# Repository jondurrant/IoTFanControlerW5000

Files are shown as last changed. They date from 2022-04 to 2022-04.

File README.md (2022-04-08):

# IoTFanControlerW5000
IOT Fan Controller based on RP2040 W5000 board from WizNet([WizNet W5100S Rp2040](https://www.wiznet.io/product-item/w5100s-evb-pico/))

Controls PWM fan based on environment temperature read through a DS18B20 sensor. Uses three presets to select fan speed, and a night time override speed to reduce night time noise.

Device is based on my TwinThing framework (see [twinThingRP2040W5x00](https://github.com/jondurrant/twinThingRP2040W5x00) and [TwinThingPyMQTT](https://github.com/jondurrant/TwinThingPyMQTT)). The device does not persist status or configuration in flash memory but instead publishes its state to a MQTT shadow service, which can update the device to current configuration when it attaches to the network.

# Hardware
+ [WizNet W5100S Rp2040](https://www.wiznet.io/product-item/w5100s-evb-pico/)
+ RGB Common Cathode LED
+ 3x Resistors 91R
+ DS20B18 temperature sensor
+ Resistor 4.7K
+ RotaryEncoder with Push Switch
+ 2x 10nF Capacitor for smoothing
+ OLED display 128x32 SSD1306
+ 2x 80mm 12V PWM controllable fans

# Dependencies
## C++
+ [FreeRTOS-Kernel](https://github.com/FreeRTOS/FreeRTOS-Kernel): Task management
+ [FreeRTOS-CoreMQTT-Agent](https://www.freertos.org/mqtt-agent/index.html): MQTT Library
+ [ioLibary_Driver](https://github.com/Wiznet/ioLibrary_Driver): Drivers for W5100s
+ [twinThingRP2040W5x00](https://github.com/jondurrant/twinThingRP2040W5x00)
+ [json-maker](https://github.com/rafagafe/json-maker): JSON writing for comms
+ [tiny-json](https://github.com/rafagafe/tiny-json): JSON parser
+ [RP2040PIO-DS18B20](https://github.com/jondurrant/RP2040PIO-DS18B20): Sensor library
+ [pico-ssd1306](https://github.com/daschr/pico-ssd1306): Oled Driver
+ [RtosComponents](https://github.com/jondurrant/RtosComponents): Watchdog module

## MQTT hub
+ [EMQX](https://www.emqx.io/)

## MQTT Services
+ [TwinManager](https://github.com/jondurrant/TwinThingPyMQTT)

# Folder Structur

+ src - source code for the project
+ lib - libraries used by the project
+ port - port code needed for the libraries used by the project
+ patches - patch files produced by WizNet for the ioLibrary_Driver lib
+ py - test python to interact with the IOT devices
+ schematic - Circuit schematic (no PCB design as build on prototype board)
+ 3dModels - STL files for PCB bracket, fan cover, OLED housing and Rotary Encoder housing

# Clone and Build
## Clone
'''
git clone --recurse-submodules https://github.com/jondurrant/IoTFanControlerW5000
'''

## Build
'''
mkdir build
cd build
cmake ..
make
'''

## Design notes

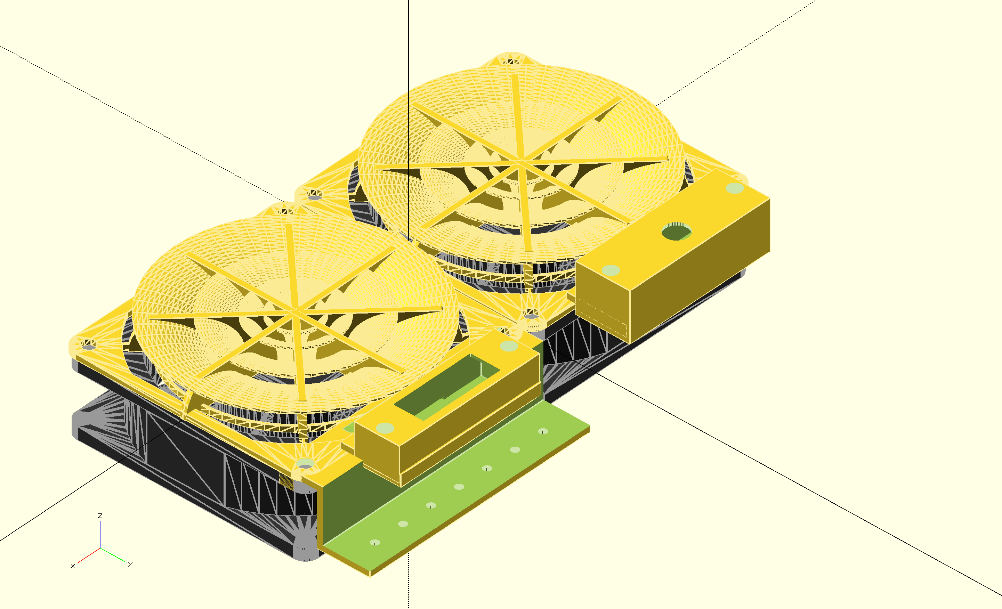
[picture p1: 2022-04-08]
3dModels/imgs/angle.png

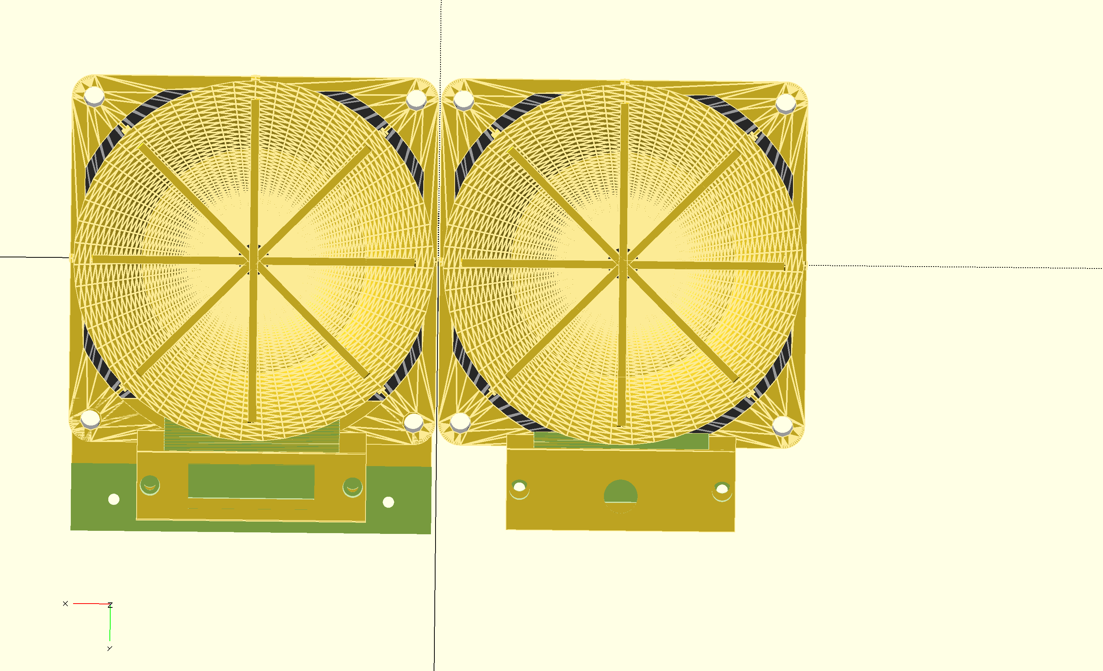
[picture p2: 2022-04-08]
3dModels/imgs/front.png

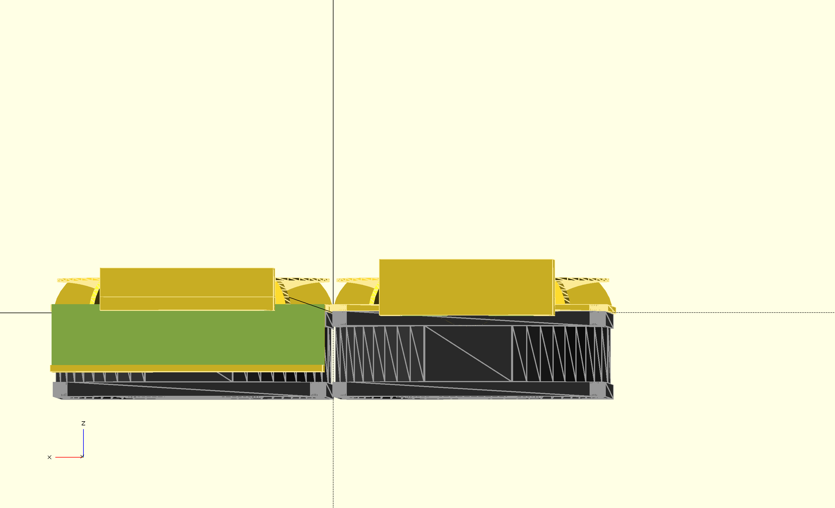
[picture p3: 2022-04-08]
3dModels/imgs/side1.png

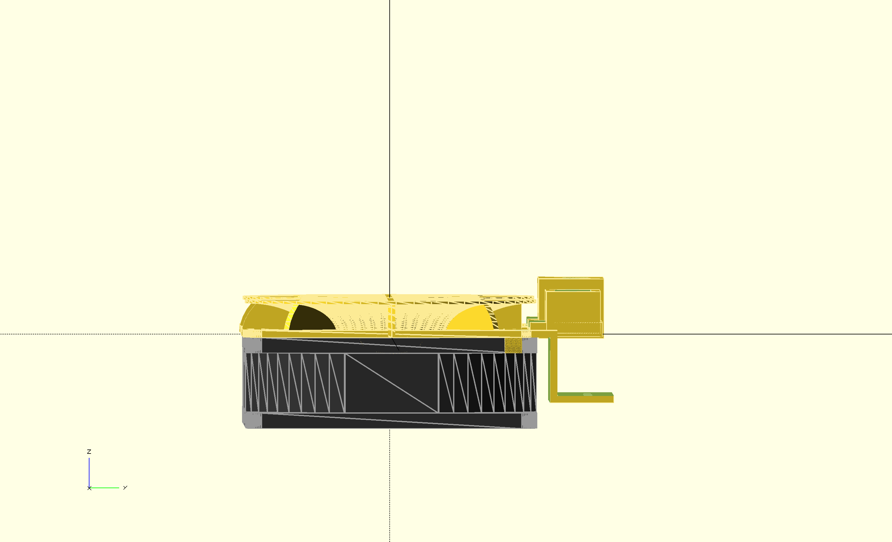
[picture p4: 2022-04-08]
3dModels/imgs/side2.png

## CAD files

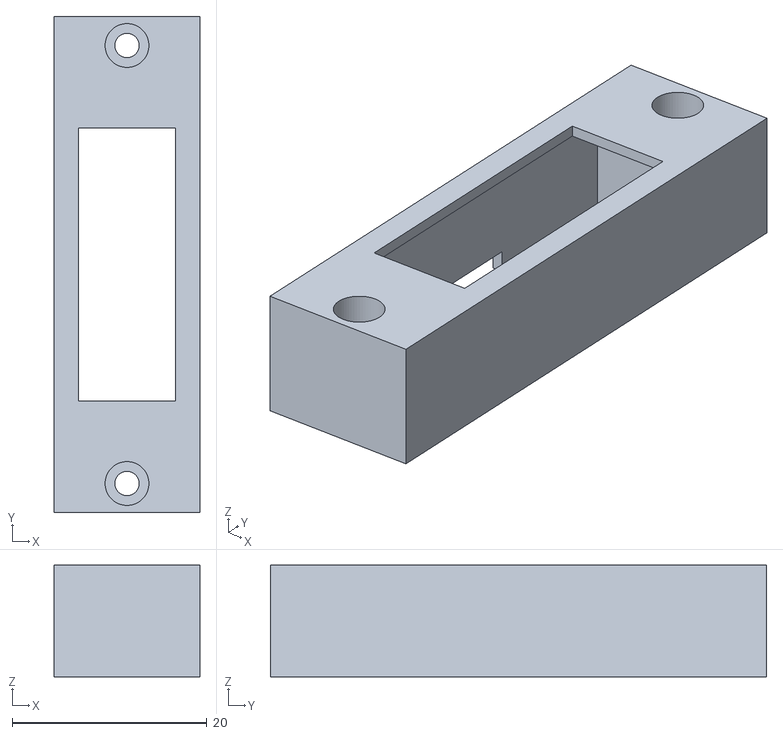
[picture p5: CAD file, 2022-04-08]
3dModels/oledHousing.stl
15.0 x 51.0 x 11.5

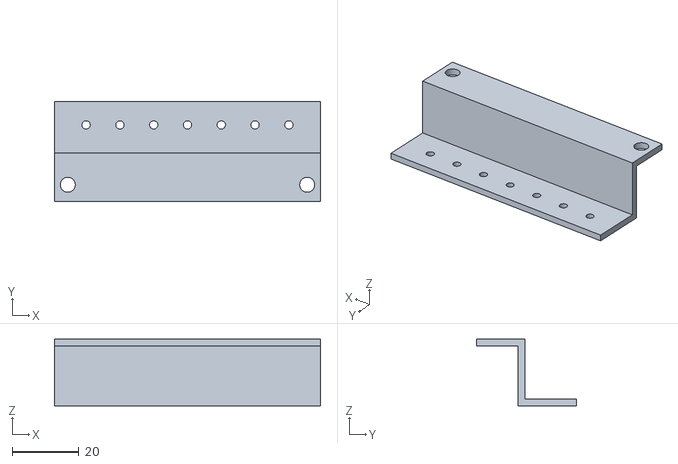
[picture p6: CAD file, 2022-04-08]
3dModels/bracket.stl
80.0 x 30.0 x 20.0

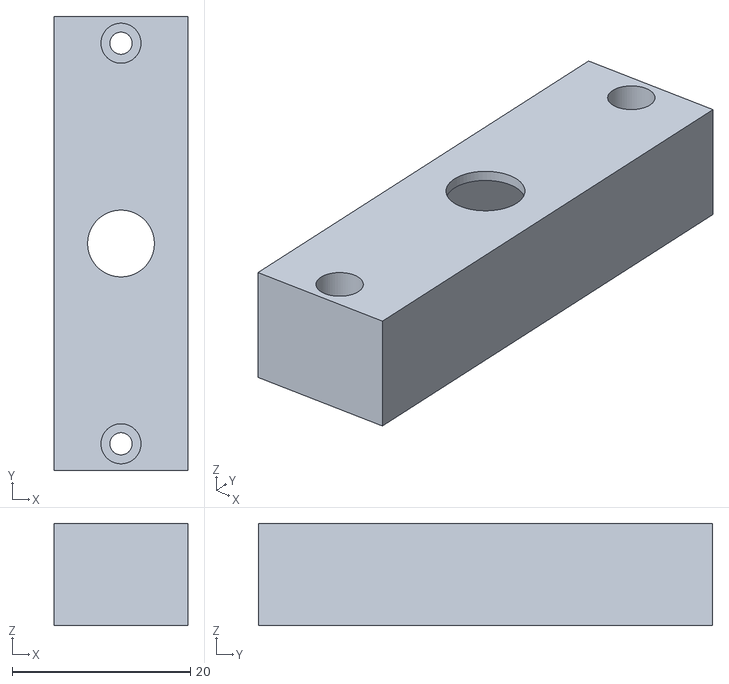
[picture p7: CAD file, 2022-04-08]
3dModels/rotEnvHousing.stl
15.0 x 51.0 x 11.5

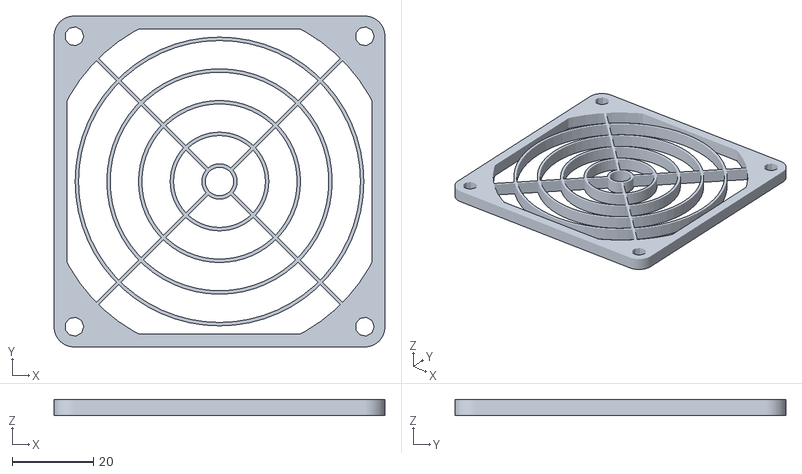
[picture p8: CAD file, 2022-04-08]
3dModels/fanGuard-Back.stl
81.5 x 81.5 x 4.00

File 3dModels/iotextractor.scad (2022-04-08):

use <../libs/openscad-rpi-library/misc_boards.scad>

/**
include <../libs/NopSCADlib/core.scad>
include <../libs/NopSCADlib/vitamins/fan.scad>
use <../libs/NopSCADlib/utils/layout.scad>
**/
include <../libs/NopSCADlib/lib.scad>  



THICK=2;
M5=5.5;
M4=4.5;
M3=3.5;
M2=2.5;
M3INSERT=3.7;
M2INSERT=3.4;

fanX=81;
fanY=81;
fanZ=26;
fanFix=35.7;

mountDep=5;


oledX=12;
oledY=38;
oledZ=3.5;
oledXD=5;

oledHouseX=oledX+THICK+1;
oledHouseY=oledY+THICK+1 + M2*4;
oledHouseZ=oledZ + 6 + THICK;


rotEncX=12;
rotEncY=38;
rotEncZ=3.5;
rotEncXD=5;

rotEncHouseX=rotEncX+THICK+1;
rotEncHouseY=rotEncY+THICK+1 + M2*4;
rotEncHouseZ=rotEncZ + 6 + THICK +5;

bracketW=30;
bracketD=20;
bracketL=80;
pcbPitch=2.54;

//fan_guard(fan80x25, name = false, thickness = THICK*2);
//translate([0,0,3])
//    oled();

fans();
bracket();

translate([-41,0,0]){
    rotate([0,0,90])
        guard();
}
translate([-41,50,(oledHouseZ+THICK)/2]){
    rotate([0,0,90])
        rotEncHouse();
}



translate([41,0,0]){
    rotate([0,0,90])
        guard();
}
translate([41,50,(oledHouseZ+THICK)/2]){
    rotate([0,0,90])
        oledHouse();
}



translate([50,0,(oledHouseZ+THICK)/2]){
//   oledHouse();
//    rotEncHouse();
}

module oled(){
    color("blue"){
        translate([0,0,(oledZ)/2])
            cube([oledX, oledY-(oledXD*2), 1], center=true);
        cube([oledX, oledY, oledZ-1], center=true);
        translate([0,(oledY-2.5)/2,5/(-2)])
            cube([oledX, 2.5, 5], center=true);
        translate([0,oledY/2-9,-5])
            cube([oledX,18,1], center=true);
    }
}


module oledHouse(){
    difference(){
        cube([oledHouseX, oledHouseY, oledHouseZ], center=true);
        cube([oledX- 2, oledY- (oledXD*2), oledHouseZ*2], center=true);
        translate([0, 0, THICK/(-2)])
            cube([oledX+1, oledY+1, oledHouseZ], center=true);
        
        for (i=[-1,1]){ 
            translate([0, (oledY/2 + M3)*i, 0]){
                cylinder(d=M2, h=oledHouseZ*2, center=true);
                translate([0, 0, 4])
                    cylinder(d=M4, h=oledHouseZ, center=true);
            }
        }
        
        translate([-6,0,oledHouseZ/(-2)]){
            cube([12,12,THICK*2],center=true);
        }
    }
}



module fans(){
    translate([0,0,25/(-2)]){
        translate([-41,0,0])
            fan(fan80x25);
        translate([41,0,0])
            fan(fan80x25);
    }
    
    //translate([0,0,50])
    //fan_guard(fan80x25, name = false, thickness = THICK);
}


module t(){
    difference(){
        translate([0,0,3/2])
            cylinder(r=2.5,h=3,center=true);
        rotate_extrude(convexity = 10)
            translate([2, 0, 0])
                circle(r = 1, $fn = 100);
        
    }
}


module guard(){
    fan_guard(fan80x25, name = false, thickness = THICK);
    
    resize(newsize=[80,80,10])
        blade();
    resize(newsize=[50,50,10])
        blade();
    resize(newsize=[28,28,10])
        blade();
    
    resize(newsize=[16,16,10])
        blade();
    
    
    intersection(){
        translate([0,0,THICK/2*5]){
            for (a=[0,45,135]){
                rotate([0,0,a])
                    cube([THICK, 82, THICK*5], center = true);
            }
            translate([-5,0,0]){
                rotate([0,0,90])
                    cube([THICK, 82, THICK*5], center = true);
            }
        }
        scale([1,1,0.5])
                sphere(d=82);
    }
    
    translate([48,0,THICK]){
        difference(){
            cube([oledHouseX+5, oledHouseY, THICK*2], center=true);
            translate([-5,0,THICK])
                cube([oledHouseX+5, oledHouseY-12, THICK*2], center=true);
            for (i=[-1,1]){ 
            translate([1, (oledY/2 + M3)*i, 0]){
                cylinder(d=M2INSERT, h=oledHouseZ*2, center=true);
            }
        }
        }
    }
}



module blade(){
    rotate_extrude(convexity = 10)
            translate([2, 0, 0])
                intersection(){
                    difference(){
                        circle(r = 1, $fn = 100);
                        circle(r = 0.9, $fn = 100);
                    }
                    translate([-1,1,1])
                        square([2,2],center=true);
                };
}




module rotEncHouse(){
    difference(){
        cube([rotEncHouseX+3, rotEncHouseY, rotEncHouseZ], center=true);
        translate([pcbPitch/2,0,0])
            cylinder(d=7.5, h=rotEncHouseZ*2, center=true);
        translate([0, 0, THICK/(-2)])
            cube([rotEncX+3, rotEncY+1, rotEncHouseZ], center=true);
        
        for (i=[-1,1]){ 
            translate([0, (rotEncY/2 + M3)*i, 0]){
                cylinder(d=M2, h=rotEncHouseZ*2, center=true);
                translate([0, 0, 4])
                    cylinder(d=M4, h=rotEncHouseZ, center=true);
            }
        }
        
        translate([-6,0,rotEncHouseZ/(-2)]){
            cube([12,12,THICK*2],center=true);
        }
    }
}


module bracket(){
    translate([41,46,(bracketD/-2)+THICK]){
        difference(){
            cube([bracketL, bracketW, bracketD], center=true); 
            
            //Front 90Deg
            translate([0,-10,THICK*(-1)]){
                cube([bracketL*1.5, bracketW/2, bracketD], center=true);
            }
            
            //Back 90Deg
            translate([0,10,THICK*(1)]){
                cube([bracketL*1.5, bracketW/2+THICK*3, bracketD], center=true);
            }
            
            //PCB Mount
            for (i=[0:pcbPitch*4:40]){
                for (j=[-1,1]){
                    translate([0+i*j,8,0]){
                        cylinder(d=M2, h=bracketD*2, center=true);
                    }
                }
            }
            
            //Fan Fixing
            for (i=[1,-1]){
                translate([36*i,-10,0]){
                    cylinder(d=M4, h=bracketD*2, center=true);
                }
            }
        }
        
    }
}

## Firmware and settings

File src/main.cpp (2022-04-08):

/**
 * ----------------------------------------------------------------------------------------------------
 * Includes
 * ----------------------------------------------------------------------------------------------------
 */
//Std
#include <stdio.h>
#include <stdlib.h>
#include <string.h>

//RP2040
#include "hardware/watchdog.h"
#include "hardware/rtc.h"


//W5000 and FreeRTOS
extern "C" {
#include <FreeRTOS.h>
#include <task.h>
#include <semphr.h>

#include "port_common.h"

#include "wizchip_conf.h"
#include "w5x00_spi.h"

#include "dhcp.h"
#include "dns.h"

#include "timer.h"
#include "socket.h"
}


//JD Specials
#include <WatchdogBlinkAgent.h>
#include <RGBLEDAgent.h>
#include "OledDisplay.h"

//TwinThing
#include "EthHelper.h"
#include "MQTTAgent.h"
#include "MQTTRouterPing.h"
#include "MQTTRouterTwin.h"

// Fan Control Classes
#include "FanState.h"
#include "RGBLEDMgr.h"
#include "FanController.h"
#include "DisplayAgent.h"
#include "RotEncAgent.h"
#include "RotEncListener.h"

/**
 * ----------------------------------------------------------------------------------------------------
 * Definitions
 * ----------------------------------------------------------------------------------------------------
 */
/* Task */
#define DHCP_TASK_STACK_SIZE 2048
#define DHCP_TASK_PRIORITY 8

#define DNS_TASK_STACK_SIZE 512
#define DNS_TASK_PRIORITY 10

/* Clock */
#define PLL_SYS_KHZ (133 * 1000)


/* Socket */
#define SOCKET_DHCP 0
#define SOCKET_DNS 3

/* Retry count */
#define DHCP_RETRY_COUNT 5
#define DNS_RETRY_COUNT 5


#ifndef MQTTHOST
#define MQTTHOST "mqtt.home.com"
#define MQTTPORT 1883
#define MQTTUSER "MAC"
#define MQTTPASSWD "MAC"
#endif


/**
 * ----------------------------------------------------------------------------------------------------
 * Variables
 * ----------------------------------------------------------------------------------------------------
 */
/* Network */
static uint8_t g_ethernet_buf[ETHERNET_BUF_MAX_SIZE] = {
    0,
};

/*NTP Servers*/
static const char *sntpHosts[5] = {
		"mqtt.home.com",
		"uk.pool.ntp.org",
		"time.cloudflare.com",
		"ntp2a.mcc.ac.uk",
		"ntp2b.mcc.ac.uk"};

TaskHandle_t initHandle = NULL;

//Global Twin Objects
EthHelper gEth;
MQTTAgent mqttAgent = MQTTAgent(3, &gEth);
MQTTRouterTwin mqttRouter;

FanState state;
TwinTask xTwin;
MQTTPingTask xPing;

RGBLEDAgent ledAgent = RGBLEDAgent(5,3,2);
RGBLEDMgr   ledMgr = RGBLEDMgr(&ledAgent);

OledDisplay display = OledDisplay(14, 15);
DisplayAgent dispAgent = DisplayAgent(&display, &state, &gEth);

FanController fanControl = FanController(&state, 0);

RotEncAgent rotEncAgent = RotEncAgent(12, 11, 10, 20);
RotEncListener rotEncListener;

/**
 * ----------------------------------------------------------------------------------------------------
 * Functions
 * ----------------------------------------------------------------------------------------------------
 */

/* Clock */
static void set_clock_khz(void);


/***
 * Print status and stack usage of task
 * @param name
 * @param task
 */
void debugTask(char * name, TaskHandle_t task){
	TaskStatus_t xTaskStatus;
	char ready[]="eReady";
	char run[]="eRunning";
	char block[]="eBlocked";
	char sus[]="eSuspended";
	char del[]="eDeleted";
	char other[]="Unknown";
	char *state = other;


	vTaskGetInfo( task,
	              &xTaskStatus,
				  pdTRUE,
				  (eTaskState)eInvalid);

	switch(xTaskStatus.eCurrentState){
	case eReady:
		state = ready;
		break;
	case eRunning:
		state = run;
		break;
	case eBlocked:
		state = block;
		break;
	case eSuspended:
		state = sus;
		break;
	case eDeleted:
		state = del;
		break;
	default:
		state = other;
	}

	printf("%s: Priority: %d/%d Run: %d Min: %d eState: %s\n",
			name,
			xTaskStatus.uxCurrentPriority,
			xTaskStatus.uxBasePriority,
			xTaskStatus.ulRunTimeCounter,
			xTaskStatus.usStackHighWaterMark,
			state
			);
}


/***
 * Start up the MQTT components
 * @param mqttTarget - Host of MQTT Hub
 * @param mqttPort - Port number
 * @param mqttUser - User
 * @param mqttPwd - Password
 */
void doMQTT(char * mqttTarget, uint16_t mqttPort, char * mqttUser, char * mqttPwd){

	mqttAgent.credentials(mqttUser, mqttPwd);
	mqttRouter.init(mqttAgent.getId(), &mqttAgent);

	//Twin agent to manage the state
	xTwin.setStateObject(&state);
	xTwin.setMQTTInterface(&mqttAgent);
	xTwin.start(tskIDLE_PRIORITY+1);

	//Start up a Ping agent to mange ping requests
	xPing.setInterface(&mqttAgent);
	xPing.start(tskIDLE_PRIORITY+1);

	//Give the router the twin and ping agents
	mqttRouter.setTwin(&xTwin);
	mqttRouter.setPingTask(&xPing);

	//Setup and start the mqttAgent
	mqttAgent.setObserver(&ledMgr);
	mqttAgent.setRouter(&mqttRouter);

	mqttAgent.connect(mqttTarget, 1883, true, false);
	mqttAgent.start(tskIDLE_PRIORITY+2);//DHCP_TASK_PRIORITY);
}


/***
 * Init thread to get everything going and check on status of network
 * @param pvParameters
 */
void
init_thread(void* pvParameters) {
	char mqttTarget[] = MQTTHOST;
	uint16_t mqttPort = MQTTPORT;
	char mqttUser[] = MQTTUSER;
	char mqttPwd[] = MQTTPASSWD;
	uint8_t ip[4];
	bool retval;

	WatchdogBlinkAgent watchdog;
	watchdog.start(tskIDLE_PRIORITY+1);


	if (!ledAgent.start(tskIDLE_PRIORITY+1)){
		LogError(("Led Agent failed to start"));
	} else {
		LogInfo(("Led Agent Started"));
	}
	ledAgent.set(RGBModeOn,0xFF,0x0,0x0);

	ledMgr.setDisplayAgent(&dispAgent);
	dispAgent.start(tskIDLE_PRIORITY+1);

	rotEncAgent.setListener(&dispAgent);
	rotEncAgent.start(tskIDLE_PRIORITY+1);

	gEth.enableMutex();
	gEth.dhcpClient();
	gEth.getIPAddress(ip);
	dispAgent.showIP(ip);
	ledAgent.set(RGBModeOn,0xFF,0xCE,0x42);

	gEth.setSNTPServers(sntpHosts, 5);
	retval = gEth.syncRTCwithSNTP(sntpHosts, 5);
	printf("SNTP Res: %s\n", retval?"Ok":"Fail");

	doMQTT(mqttTarget, mqttPort, mqttUser, mqttPwd);

	uint32_t count=0;
	datetime_t xDate;
    for (;;){
    	vTaskDelay(1000);

    	/*
    	debugTask("ledAgent", ledAgent.getTask());
    	debugTask("watchdog", watchdog.getTask());
    	debugTask("mqttAgent", mqttAgent.getTask());
    	debugTask("xTwin", xTwin.getTask());
    	debugTask("xPing", xPing.getTask());
    	debugTask("init", initHandle);
    	debugTask("dispAgent", dispAgent.getTask());
    	debugTask("rotEncAgent", rotEncAgent.getTask());
    	*/

    	//Check if network has failed
    	if (!gEth.isJoined()){
    		dispAgent.noIP();
    		ledAgent.set(RGBModeOn,0xFF,0x0,0x0);
    		gEth.dhcpClient();
    		if (gEth.isJoined()){
				ledAgent.set(RGBModeOn,0xFF,0xCE,0x42);
				gEth.getIPAddress(ip);
				dispAgent.showIP(ip);
    		}
    	} else {

    		//Once a day renew the DHCP lease
			if (count >= 60*60*24){
				count = 0;

				if (gEth.dhcpClient()){
					printf("DHCP Renewed\n");
				} else {
					printf("DHCP FAILED Renew\n");
				}

				//And update RTC
				retval = gEth.syncRTCwithSNTP(sntpHosts, 5);
				printf("SNTP: %s\n", retval?"Ok":"Fail");
			}
    	}
    	count ++;

    	if (count % 10 == 0){
			state.updateClock();
    	}
    }
}

/**
 * ----------------------------------------------------------------------------------------------------
 * Main
 * ----------------------------------------------------------------------------------------------------
 */
int main()
{
    /* Initialize */
    set_clock_khz();

    stdio_init_all();


    //3second wait to let serial stabalise for debug messages
    sleep_ms(3000);

    if (watchdog_caused_reboot()){
    	printf("WATCHDOG REBOOTED\n");
    	sleep_ms(5000);

    }

    //Init ethernet before running up tasks
    gEth.rtcInit();
    gEth.init(g_ethernet_buf);

    //Nice message on display why waiting for network
    display.displayString("Hello","",2);


    //Launch Init task
    xTaskCreate(
		init_thread,
		"Init task",
		DHCP_TASK_STACK_SIZE,
		( void * ) 1,
		DHCP_TASK_PRIORITY,//tskIDLE_PRIORITY+1,
		&initHandle );

    vTaskStartScheduler();

    //Should never get here
    while (1)
    {
        ;
    }
}


/* Clock */
static void set_clock_khz(void)
{
    // set a system clock frequency in khz
    set_sys_clock_khz(PLL_SYS_KHZ, true);

    // configure the specified clock
    clock_configure(
        clk_peri,
        0,                                                // No glitchless mux
        CLOCKS_CLK_PERI_CTRL_AUXSRC_VALUE_CLKSRC_PLL_SYS, // System PLL on AUX mux
        PLL_SYS_KHZ * 1000,                               // Input frequency
        PLL_SYS_KHZ * 1000                                // Output (must be same as no divider)
    );
}

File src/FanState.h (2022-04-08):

/*
 * FanState.h
 *
 * Fan State
 *
 *  Created on: 14-Mar- 2022
 *      Author: jondurrant
 */

#ifndef FANSTATE_H_
#define FANSTATE_H_

#include <MQTTConfig.h>
#include "StateTemp.h"
#include <stdbool.h>
#include <stdint.h>
#include <DS18B20.h>

#define FAN_ON_SLOT 		3
#define FAN_DAY_END_SLOT 	4
#define FAN_DAY_START_SLOT	5
#define FAN_DAY_SLOT 		6
#define FAN_CLOCK_SLOT		7
#define FAN_CSPEED_SLOT		8
#define FAN_MAX_NIGHT_SLOT	9
#define FAN_PRE_TEMP_SLOT	10
#define FAN_PRE_SPEED_SLOT	11
#define FAN_ENV_TEMP_SLOT	12
#define FAN_OVERRIDE_SLOT	13


#define FAN_PRESETS 3

/***
 * State include temperate, Fan Speed
 */
class FanState: public StateTemp {
public:
	FanState();
	virtual ~FanState();

	/***
	 * calculate Speed
	 * @return
	 */
	void calcSpeed();

	/***
	 * Gets the On status of the fan
	 * @return
	 */
	bool getOn() const;

	/***
	 * Sets the on status of the fan
	 * @param b
	 */
	void setOn(bool b);

	/***
	 * Returns hour at which Day Ends
	 * @return
	 */
	uint8_t getDayEnd() const ;

	/***
	 * Sets hour at which day ends
	 * @param DayEnd
	 */
	void setDayEnd(uint8_t xDayEnd = 21) ;

	/***
	 * Get Start Day Hour
	 * @return start hour
	 */
	uint8_t getDayStart() const ;

	/***
	 * Sets Day start hour
	 * @param xDayStart
	 */
	void setDayStart(uint8_t xDayStart = 7) ;

	/***
	 * Is in day mode
	 * @return
	 */
	bool isDay() const ;

	/***
	 * Set day mode
	 * @param xDay
	 */
	void setDay(bool xDay = true) ;


	/***
	 * Get Environment Temperature (DS18B20)
	 * @return celsius
	 */
	float getEnvTemp();


	/***
	 * Set temp in celsius
	 * @param temp
	 */
	void setEnvTemp(float temp);

	/***
	 * Number of minutes left for fan speed override
	 * @return
	 */
	uint16_t getOverrideMinutes();

	/***
	 * Set number of minutes to override fan speed for
	 * @param min
	 */
	void setOverrideMinutes(uint16_t min);


	/***
	 * Update time and temp and trigger state update
	 */
	void updateClock();


	/***
	 * Get Current speed
	 * @return percentage 0 to 100
	 */
	uint8_t getCurrentSpeed();

	/***
	 * Set Current Speed
	 * @param percent: 0 to 100
	 */
	void setCurrentSpeed(uint8_t percent);

	/***
	 * Get Maximum speed to run at night
	 * @return perecntage 0 to 100
	 */
	uint8_t getMaxNightSpeed();

	/***
	 * Set Maximum speed to run at night
	 * @param percent - 0 to 100
	 */
	void setMaxNightSpeed(uint8_t percent);

	/***
	 * Get Temperate presets
	 * When temp < t[0] speed is zero
	 * When t[i] <= temp < t[i+1]: speed is speed[i[
	 * When temp > t[2]: speed is speed[2]
	 * @return uint8_t[3]
	 */
	const uint8_t * getPreTemp() const;

	/***
	 * Set Temperature presets
	 * @param temps - uint8_t[3]
	 */
	void setPreTemp(uint8_t* temps);

	/***
	 * Set specific temp preset
	 * @param temp - tempereature
	 * @param preset - 0 to 2.
	 */
	void setPreTemp(uint8_t temp, uint8_t preset);

	/***
	 * Get preset speed
	 * @return uintt_t[3], each value 0 to 100
	 */
	const uint8_t * getPreSpeed() const;

	/***
	 * Set preset speeds
	 * When temp < t[0] speed is zero
	 * When t[i] <= temp < t[i+1]: speed is speed[i[
	 * When temp > t[2]: speed is speed[2]
	 * @param speeds uint8_t[3] - each value 0 to 100
	 */
	void setPreSpeed(uint8_t* speeds);

	/***
	 * Set specific preset speed
	 * @param speed - 0 to 100
	 * @param preset 0 to 2
	 */
	void setPreSpeed(uint8_t speed, uint8_t preset);



	/***
	 * Update state data from a json structure
	 * @param json
	 */
	virtual void updateFromJson(json_t const *json);

	/***
	 * Retrieve state of object in JSON format
	 * @param buf - buffer to write to
	 * @param len - length of buffer
	 * @return length of json or zero if we ran out of space
	 */
	virtual unsigned int state(char *buf, unsigned int len) ;


protected:
	/***
	 *  On status in JSON format
	 * @param buf
	 * @param len
	 * @return
	 */
	char* jsonOn(char *buf, unsigned int len);

	/***
	 *  Day Start Hour status in JSON format
	 * @param buf
	 * @param len
	 * @return
	 */
	char* jsonDayStart(char *buf, unsigned int len);

	/***
	 *  Day End Hour status in JSON format
	 * @param buf
	 * @param len
	 * @return
	 */
	char* jsonDayEnd(char *buf, unsigned int len);

	/***
	 *  Day in JSON format
	 * @param buf
	 * @param len
	 * @return
	 */
	char* jsonDay(char *buf, unsigned int len);

	/***
	 *  Time in JSON format
	 * @param buf
	 * @param len
	 * @return
	 */
	char* jsonClock(char *buf, unsigned int len);

	/***
	 *  Current Speed in JSON format
	 * @param buf
	 * @param len
	 * @return
	 */
	char* jsonCSpeed(char *buf, unsigned int len);

	/***
	 *  Max Night Speed in JSON format
	 * @param buf
	 * @param len
	 * @return
	 */
	char* jsonMSpeed(char *buf, unsigned int len);

	/***
	 *  Preset Temp in JSON format
	 * @param buf
	 * @param len
	 * @return
	 */
	char* jsonPreTemp(char *buf, unsigned int len);

	/***
	 *  Preset Speed in JSON format
	 * @param buf
	 * @param len
	 * @return
	 */
	char* jsonPreSpeed(char *buf, unsigned int len);

	/***
	 *  Preset Speed in JSON format
	 * @param buf
	 * @param len
	 * @return
	 */
	char* jsonEnvTemp(char *buf, unsigned int len);

	/***
	 * Fan speed override time in minutes JSON format
	 * @param buf
	 * @param len
	 * @return
	 */
	char* jsonOverrideMinutes(char *buf, unsigned int len);

private:
	//Is Fan on
	bool xOn = false;

	//Day start and end
	uint8_t xDayStart = 7;
	uint8_t xDayEnd = 21;
	bool xDay = true;

	//Fan Speed
	uint8_t xCSpeed = 100;
	uint8_t xMSpeed = 100;

	//Presets
	uint8_t xPreTemp[FAN_PRESETS];
	uint8_t xPreSpeed[FAN_PRESETS];

	//Environment temp read by DS18B20
	float xEnvTemp = 0.0;

	//Hardware interface
	DS18B20 xDS18B20 ;

	uint8_t xMin = 0;
	uint16_t xOverrideMinutes = 0;

};

#endif /* STATETEMP_H_ */

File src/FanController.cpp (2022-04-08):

/*
 * FanController.cpp
 *
 * PWM Fan Controller
 *
 *  Created on: 15 Mar 2022
 *      Author: jondurrant
 */

#include "FanController.h"
#include "hardware/pwm.h"


/***
 * Constructor
 * @param state - State object used to find speed
 * @param gp - GPIO number for PWM pin
 */
FanController::FanController(FanState *state, uint8_t gp) {
	xPin = gp;
	pState = state;

	pState->attach(this);

	 gpio_set_function(xPin, GPIO_FUNC_PWM);
	 uint slice_num = pwm_gpio_to_slice_num(0);
	 pwm_set_enabled(slice_num, true);
	 pwm_set_gpio_level	(xPin,0);
}

/***
 * Destructor
 */
FanController::~FanController() {
	// TODO Auto-generated destructor stub
}


/***
 * Notification of a change of a state item with the State object.
 * @param dirtyCode - Representation of item changed within state. Used to pull back delta
 */
void FanController::notifyState(uint16_t dirtyCode){
	if ((dirtyCode | FAN_CSPEED_SLOT) > 0){
		uint8_t speed = pState->getCurrentSpeed();

		uint16_t s = 0xffff/100;
		uint16_t minSpeed = s * 20;
		s = (0xffff - minSpeed)/100;
		s = (speed * s) + minSpeed;

		if (speed == 0){
			s = 0;
		}

		if (!pState->getOn()){
			s = 0;
		}
		pwm_set_gpio_level	(xPin, s);

	}
}

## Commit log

2022-03-15 RGB Status LED added
2022-03-15 Fan control added
2022-03-15 Fan control
2022-03-25 Added external DS18B20 temp sensor
2022-03-28 DisaplyAgent stack overflow resolved
    [main.cpp]
2022-03-28 Rotary Encoder framework added
2022-03-31 Override time added. Issue with getting time sometimes from SNTP
    [FanState.h, RotEncAgent.cpp]
2022-03-31 Has NTP issue but othersie seems to be working
    [main.cpp]
2022-04-04 Fix SNTP issue
    [IoTFanControl.kicad_pcb, IoTFanControl.kicad_sch, IoTFanControl.sch]
2022-04-08 Added 3d files and readme
    [bracket.stl, fanGuard-Back.stl, iotextractor.scad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]
